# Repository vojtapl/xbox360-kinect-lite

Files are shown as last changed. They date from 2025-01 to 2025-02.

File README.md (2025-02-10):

# Pcb and Case for Shrinking the Xbox 360 Kinect
This repository contains a PCB and a basic case for using only the camera board from the Xbox 360 Kinect.

I have recently read [this great article](https://medium.com/robotics-weekends/how-to-turn-old-kinect-into-a-compact-usb-powered-rgbd-sensor-f23d58e10eb0), which lays out the idea of making a *Kinect Lite* from an old Xbox 360 Kinect by isolating the camera board, which can function separately. As I saw one being sold for next to nothing with a broken tilt motor, I thought it would be a great idea to implement the ideas mentioned in the article. The repository contains the PCB (including LCSC part numbers), which generates all the necessary voltage rails, and a basic 3D-printable case.

## What might need improving
- The case model is a bit crude, as I used this as a opportunity to learn some basics of FreeCAD. Also, the camera PCB screws do not seem to be arranged in a rectangle, so one of the mounting holes might need enlarging.
- The case walls are a bit too long and flex a bit when squeezed.
- I am uncertain whether the fan and the fuse (not really sure what exactly it is) on the IR transmitter is really needed.

## Assembly
0. Acquire the Xbox 360 Kinect, make the PCB, and print the case.
1. Tear down the Kinect. [Example video.](https://youtu.be/PgViFpEWwBA)
2. What we will need from it is the PCB to which the cameras are connected (without the LED, as it connects to a PCB which we will not use), the aluminum chassis with the cameras, the cooling fan, some of the screws and standoffs, and the lens plastic holder with the lenses.
3. Cover the cameras and the IR transmitter with tape and cut the aluminum chassis with a saw next to the cameras. One cut will be next to the two cameras - when looking from the inside - right next to the white plastics, and the other will just remove the bent part next to the IR transmitter. See the photos of how it should look afterward. Remember to clean everything from the shavings.

cut chassis

4. Get the case and add the lenses (note that the IR projector one has a small notch) and insert them into the case. Add the plastic holder on top and screw it in (it might need a corner cut).
5. Insert the PCB correctly onto the camera PCB - either use the standoffs with the included screws and then push the small connector in, or push the connector in first so that the small connector connects to the middle pins (with one row on the left and one on the right unconnected). Now is a good time to test things out.
6. Screw the camera PCB into the cut aluminum chassis and connect the cameras, fan, and the IR transmitter (every cable should be connected by now).
7. Insert the fan with the cable sticking up and the rubber padding away from the air intake.

case with fan

8. Screw in the chassis assembly.
9. Screw in the back plate, and you are done.

## Power consumption
The measurements were made with KWS-2301C, a cheap USB-C power meter.
- Idle
Idle power consumption
- Running with `freenect-regview`
Idle power consumption

## Images
On the ruler look at the top scale, as that one is in centimeters.
- View from right
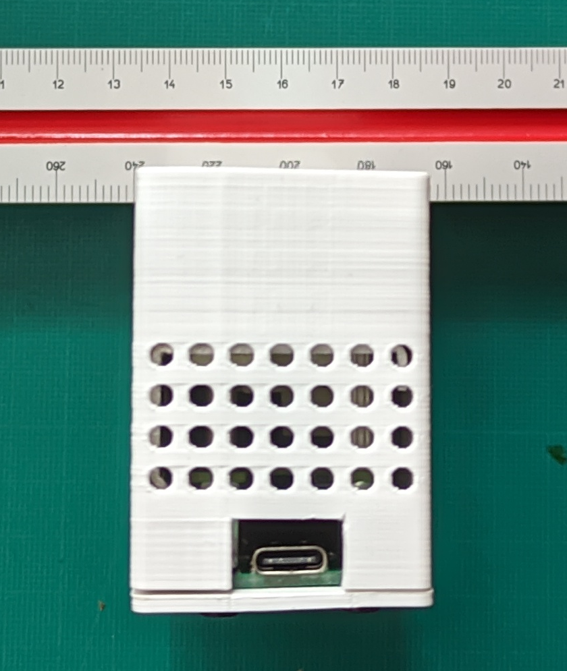
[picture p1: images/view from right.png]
View from right

- View from side
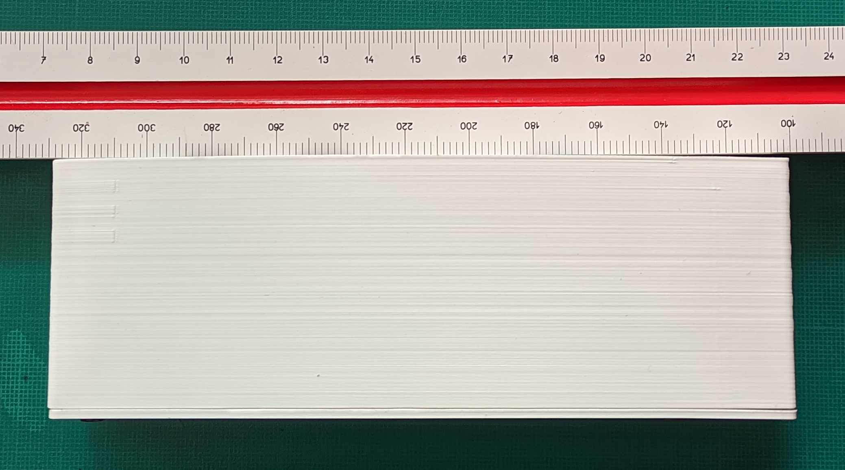
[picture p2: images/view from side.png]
View from side

- View from above
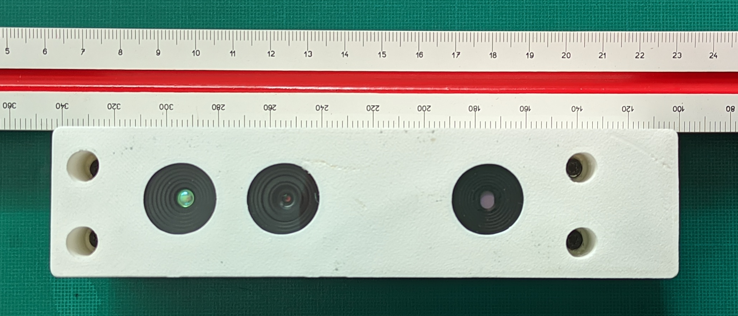
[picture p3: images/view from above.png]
View from above

- PCB
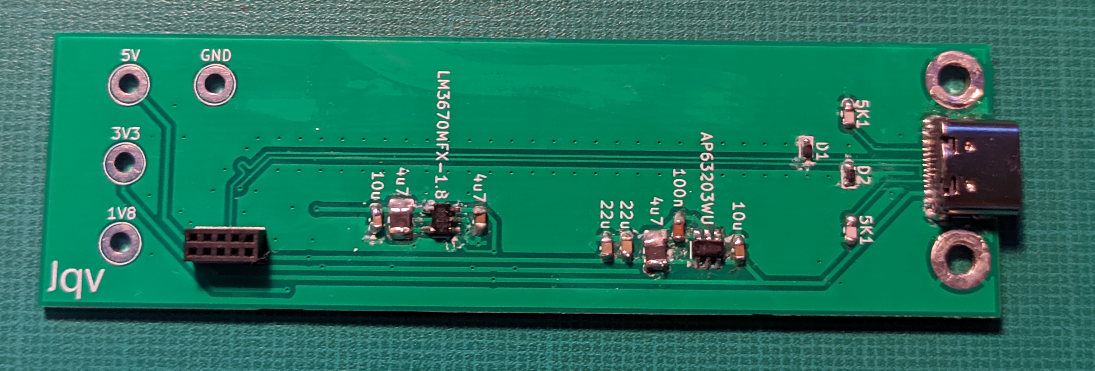
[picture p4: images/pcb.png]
PCB


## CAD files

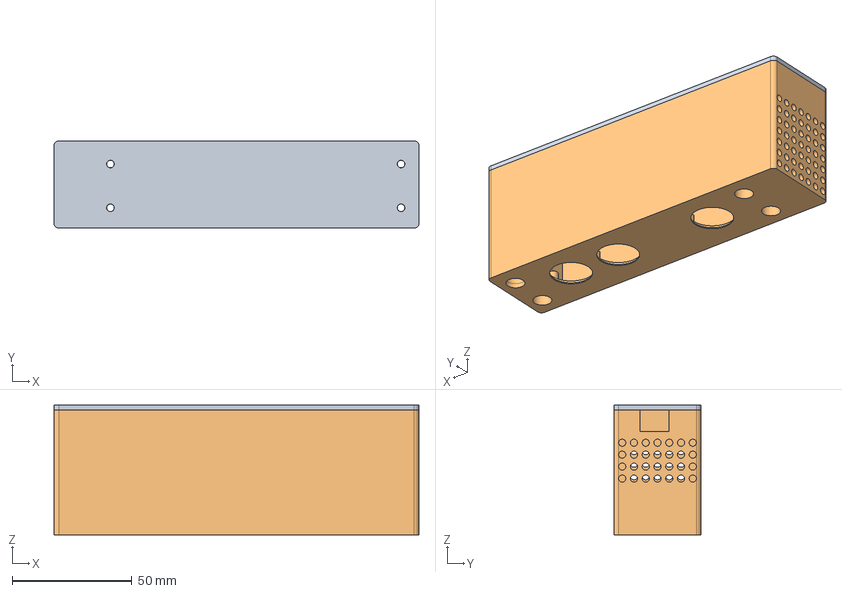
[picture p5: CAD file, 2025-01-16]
case.FCStd
152.6 x 36.5 x 54.2 mm
case lid
case

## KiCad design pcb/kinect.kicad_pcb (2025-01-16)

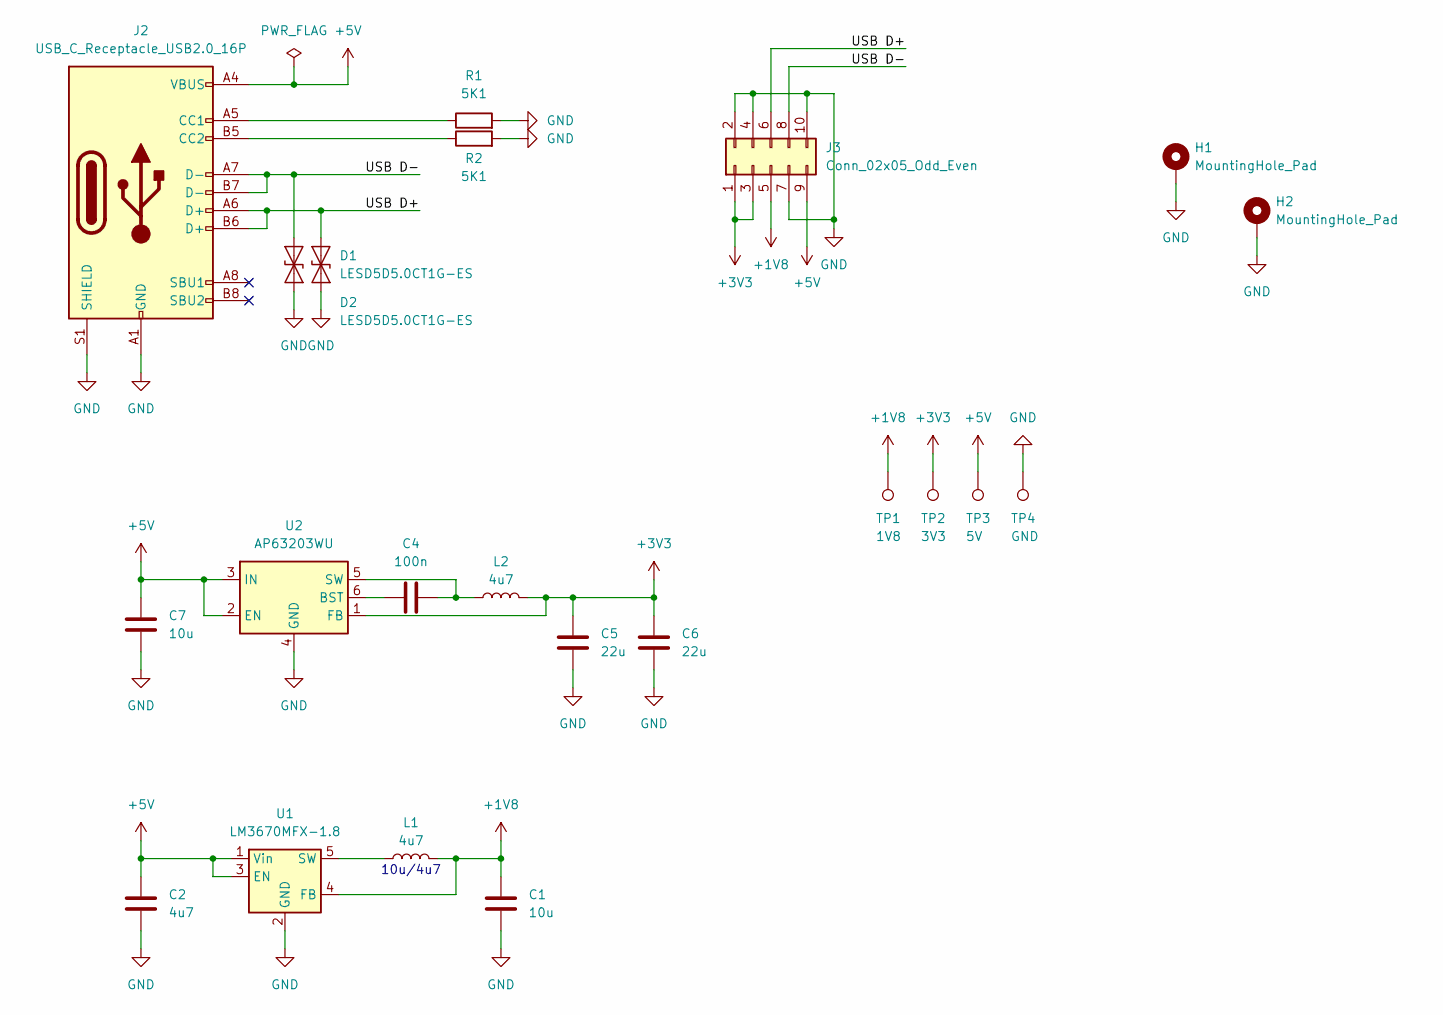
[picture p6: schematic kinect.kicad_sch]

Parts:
C1, C7: 10u; C_0603_1608Metric_Pad1.08x0.95mm_HandSolder; LCSC C1691
C2: 4u7; C_0603_1608Metric_Pad1.08x0.95mm_HandSolder; LCSC C2918489
C4: 100n; C_0603_1608Metric_Pad1.08x0.95mm_HandSolder
C5, C6: 22u; C_0603_1608Metric_Pad1.08x0.95mm_HandSolder; LCSC C59461
D1, D2: LESD5D5.0CT1G-ES; D_SOD-523; LCSC C5199159
H1, H2: MountingHole_Pad; MountingHole_3.2mm_M3_DIN965_Pad
J2: USB_C_Receptacle_USB2.0_16P; USB_C_Receptacle_G-Switch_GT-USB-7010ASV; LCSC C393939
J3: Conn_02x05_Odd_Even; PinSocket_2x05_P1.27mm_Vertical; LCSC C2935883
L1, L2: 4u7; L_1008_2520Metric_Pad1.43x2.20mm_HandSolder; LCSC C315719
R1, R2: 5K1; R_0603_1608Metric_Pad0.98x0.95mm_HandSolder; LCSC C113390
TP1: 1V8; TestPoint_Loop_D2.50mm_Drill1.85mm
TP2: 3V3; TestPoint_Loop_D2.50mm_Drill1.85mm
TP3: 5V; TestPoint_Loop_D2.50mm_Drill1.85mm
TP4: GND; TestPoint_Loop_D2.50mm_Drill1.85mm
U1: LM3670MFX-1.8; TSOT-23-5; LCSC C2071285
U2: AP63203WU; TSOT-23-6; LCSC C780769

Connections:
+1V8: C1.1, J3.5, L1.2, TP1.1, U1.4 (FB)
+3V3: C5.1, C6.1, J3.1, J3.3, L2.2, TP2.1, U2.1 (FB)
+5V: C2.1, C7.1, J2.A4 (VBUS), J2.A9 (VBUS), J2.B4 (VBUS), J2.B9 (VBUS), J3.9, TP3.1, U1.1 (Vin), U1.3 (EN), U2.2 (EN), U2.3 (IN)
/USB D+: D1.2 (A2), J2.A6 (D+), J2.B6 (D+), J3.6
/USB D-: D2.2 (A2), J2.A7 (D-), J2.B7 (D-), J3.8
GND: C1.2, C2.2, C5.2, C6.2, C7.2, D1.1 (A1), D2.1 (A1), H1.1, H2.1, J2.A1 (GND), J2.A12 (GND), J2.B1 (GND), J2.B12 (GND), J2.S1 (SHIELD), J3.2, J3.4, J3.7, J3.10, R1.2, R2.2, TP4.1, U1.2 (GND), U2.4 (GND)
unnamed: J2.A5 (CC1), R1.1
unnamed: J2.B5 (CC2), R2.1
unnamed: L1.1, U1.5 (SW)
unnamed: C4.2, U2.6 (BST)
unnamed: C4.1, L2.1, U2.5 (SW)

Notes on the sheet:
10u/4u7

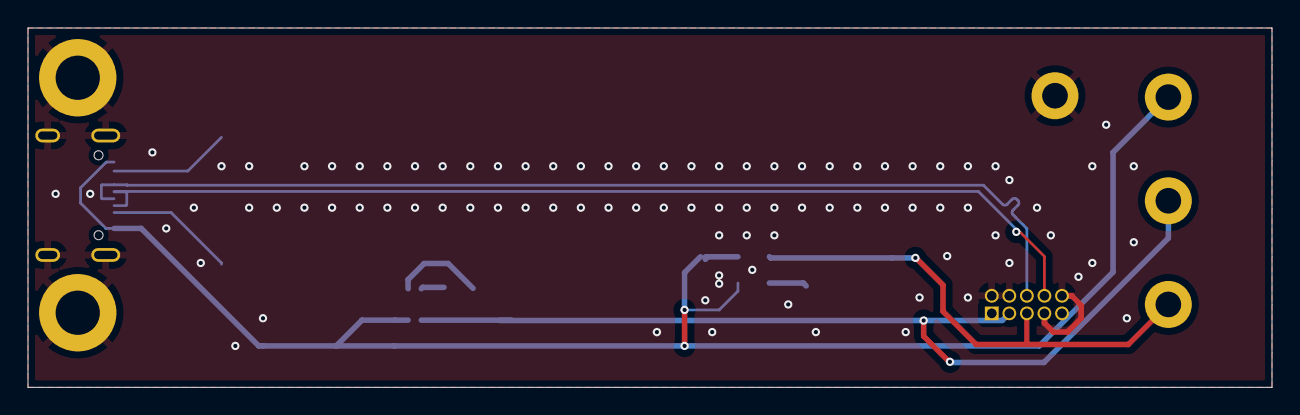
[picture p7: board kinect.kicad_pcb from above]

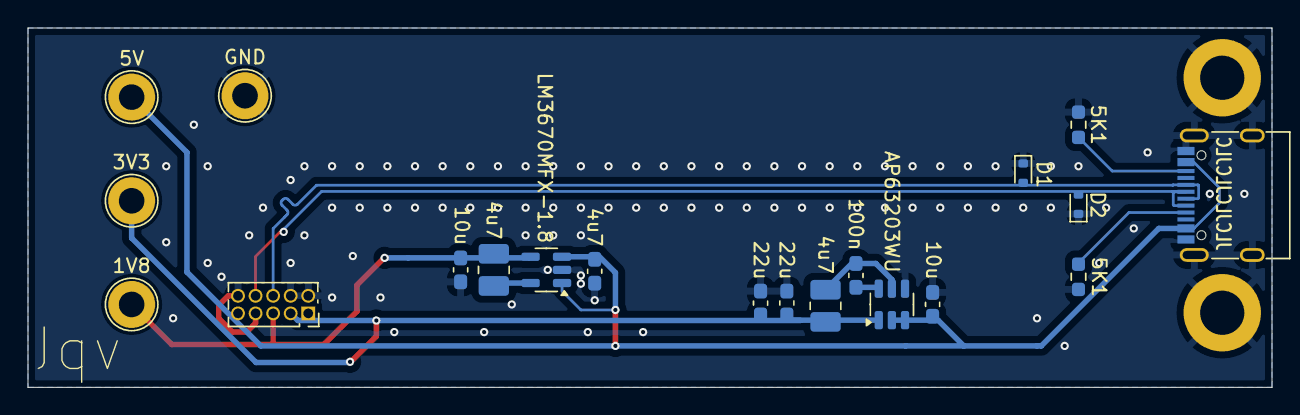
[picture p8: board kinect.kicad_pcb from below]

Board: 2 copper layers, 90.0 x 26.0 mm, 22 parts (20 on the bottom side), 11 nets.

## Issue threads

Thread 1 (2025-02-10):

PCB availability

jekkos, 2025-02-10:
Hi, I found this repo through the blogpost on Kinect Lite. I was about to convert one myself but then found that I needed to solder directly to the connector pads as no instructions were really given in the original blogpost.

Does the PCB here contain a connector for the camera board? It would be more convenient as I'm not sure my soldering skills are up to this job otherwise. I briefly searched for this specific connector but could not retrieve the part number for it.

Also can I order the PCB you made somehwere or do you have a suggestion which service I could use? Regarding the case there is already one on printables which you might not be aware of https://www.printables.com/model/229689-kinect-lite

It does not have USB-c yet but I was planning to adapt that one, but might change plans now I found this repo.

vojtapl, 2025-02-10:
Hi!

> Does the PCB here contain a connector for the camera board?
Yes it does, I have added a photo of the pcb to the repo's readme, which shows it.

> I briefly searched for this specific connector but could not retrieve the part number for it.
I could not either, so there is a smaller one which fits nicely.

> Also can I order the PCB you made somhwere or do you have a suggestion which service I could use?
I have ordered my pcb on [jlcpcb.com](https://jlcpcb.com/), as if I order it with the components at [lcsc.com](https://www.lcsc.com/) I pay for only one shipping. If you do not need to modify it, live within Europe and pay for the shipping, I can send you the pcb.

jekkos, 2025-02-10:
Ok that is very nice, actually this PCB would increase my chances of getting it to work. First I like to test if I can connect the device to USB-c this way before printing the enclosure.

I checked the PCB and seems it has the two voltage regulators and a USB-c connector. That should suffice. I am located in Belgium. Do you have Paypal? You can send me a payment request there. Or I can send it over a blockchain or wire transfer, whatever you prefer.

vojtapl, 2025-02-11:
Can I send you an email or message on discord/matrix?

jekkos, 2025-02-11:
you can send me an email on jeroen @ peelaerts.eu

jekkos, 2025-02-12:
Perhaps try email as I'm not certain if matrix works correctly in my browser

devilbash, 2025-07-21:
Do you have another PCB?
is very good work!
Thanks

vojtapl, 2025-07-21:
> Do you have another PCB? is very good work! Thanks

Currently I've got one left and in a month I'll likely order some more. The shipping price can be estimated [here](https://www.postaonline.cz/en/kalkulacka-postovneho) and if you want to, I can assemble the PCB for €4. If you're interested leave me some way of contacting you.

devilbash, 2025-07-21:
Hi,
Yes, I'm interested. My email address is marco.compostella@gmail.com
Thanks for your reply. I look forward to hearing from you.
Have a good day.

Closed 2025-05-01.

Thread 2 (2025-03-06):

Camera Type

labolaxar, 2025-03-06:
Did you use a 1414 camera? There is more than one model of the 360 Kinect camera (1473, 1414, etc.(?)), and on the Medium website I saw someone write that only a 1414 works. I just wanted to check and see which one you used.

vojtapl, 2025-03-06:
Based on Looki2000's comment on the article, I think I have the 1414 model, as there are multiple PCBs inside mine. Though I cannot be sure, as I have thrown out the plastic case.

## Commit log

2025-02-02 added photos of current consumption
2025-02-10 added photo of pcb
2026-07-09 update readme - new pcb image, thermistor
